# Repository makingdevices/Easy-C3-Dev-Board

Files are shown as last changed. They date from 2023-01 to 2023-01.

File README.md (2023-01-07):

<!-- Improved compatibility of back to top link: See: https://github.com/othneildrew/Best-README-Template/pull/73 -->

<!--
*** Thanks for checking out the Best-README-Template. If you have a suggestion
*** that would make this better, please fork the repo and create a pull request
*** or simply open an issue with the tag "enhancement".
*** Don't forget to give the project a star!
*** Thanks again! Now go create something AMAZING! :D
-->

<!-- PROJECT SHIELDS -->
<!--
*** I'm using markdown "reference style" links for readability.
*** Reference links are enclosed in brackets [ ] instead of parentheses ( ).
*** See the bottom of this document for the declaration of the reference variables
*** for contributors-url, forks-url, etc. This is an optional, concise syntax you may use.
*** https://www.markdownguide.org/basic-syntax/#reference-style-links
-->
[][ig-url]
[][sponsor-url]
[][stars-url]
[][issues-url]
[][linkedin-url]

<!-- PROJECT LOGO -->
<br />
<div align="center">
  <a href="https://makingdevices.com/links/">
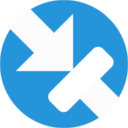
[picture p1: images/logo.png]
    
  </a>

<h3 align="center">Making Devices</h3>

  <p align="center">
    Open Source projects where we struggle with engineering, electronics, coding and who knows what else... In this case, The Easy C3 Dev Board is a development board for the esp32 C3 so I can test their capabilities, so hopefully you may find it interesting ;)
  </p>
</div>

<!-- TABLE OF CONTENTS -->
<details>
  <summary>Table of Contents</summary>
  <ol>
    <li>
      <a href="#about-the-project">About The Project</a>
      <ul>
        <li><a href="#built-with">Built With</a></li>
      </ul>
    </li>
    <li>
      <a href="#Build-one">Build one</a>
      <ul>
      </ul>
    </li>
    <li><a href="#usage">Usage</a></li>
    <li><a href="#roadmap">Roadmap</a></li>
    <li><a href="#license">License</a></li>
    <li><a href="#contact">Contact</a></li>
    <li><a href="#Sponsor">Sponsor</a></li>
  </ol>
</details>

<!-- ABOUT THE PROJECT -->
## About The Project

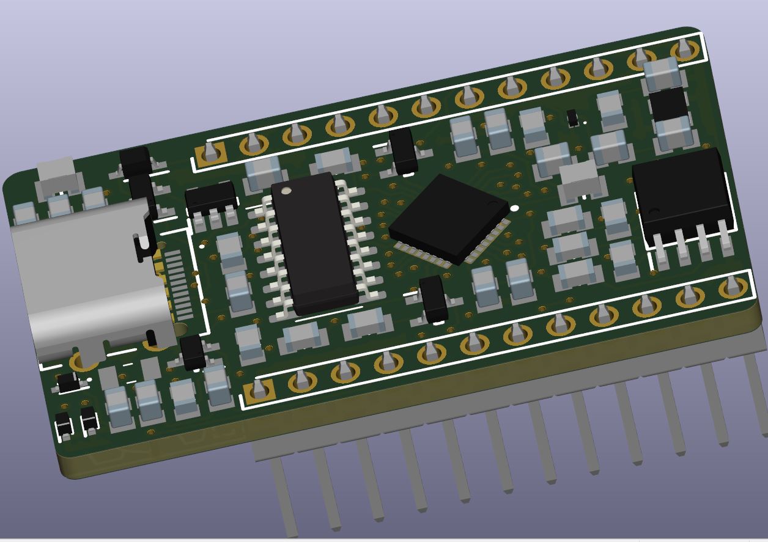
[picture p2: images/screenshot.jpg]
Bytes Counter Shot
[](https://github.com/makingdevices/Easy-C3-Dev-Board)

The Easy C3 Dev Board is a esp32 C3 based development board to test this microcontroller.

This device is under development, so I do encourage you to not assembly, order any PCB or use any software from this repository until the project is finished.

<p align="right">(<a href="#readme-top">back to top</a>)</p>

### Built With

[][kicad-url]
[][sponsor-url]

<p align="right">(<a href="#readme-top">back to top</a>)</p>

<!-- GETTING STARTED -->

## Build one
NOT RECOMMENDED AS THE DEVICE IS UNDER DEVELOPMENT

<p align="right">(<a href="#readme-top">back to top</a>)</p>

<!-- USAGE EXAMPLES -->
## Usage

Instructions of use:

- Not tested

<p align="right">(<a href="#readme-top">back to top</a>)</p>

<!-- ROADMAP -->
## Roadmap

- [ ] Assembly project.
- [ ] Test/validate the board

See the [open issues](https://github.com/makingdevices/Easy-C3-Dev-Board/issues) for a full list of proposed features (and known issues).

State: Project <b>UNFINISHED</b> - 08/01/2023

Priority: <b>Medium</b>

<p align="right">(<a href="#readme-top">back to top</a>)</p>

<!-- LICENSE -->
## License

Distributed under three licenses:
- [Hardware](/License/HW_cern_ohl_s_v2.pdf)
- [Software](/License/SW_GPLv3.0.txt)
- [Documentation](/License/Documentation_CC-BY-SA-4.0.txt)

[GPL v3 License][license-url] 
<p align="right">(<a href="#readme-top">back to top</a>)</p>

<!-- CONTACT -->
## Contact

Making Devices - [@MakingDevices](https://www.instagram.com/makingdevices/)

Project Link: [https://github.com/makingdevices/OpenReflowPlate](https://github.com/makingdevices/Easy-C3-Dev-Board/)

Other Links: [LinkTree](https://makingdevices.com/links/)

<p align="right">(<a href="#readme-top">back to top</a>)</p>

<!-- MARKDOWN LINKS & IMAGES -->
<!-- https://www.markdownguide.org/basic-syntax/#reference-style-links -->
[contributors-shield]: https://img.shields.io/github/contributors/makingdevices/Easy-C3-Dev-Board.svg?style=for-the-badge
[contributors-url]: https://github.com/makingdevices/Easy-C3-Dev-Board/graphs/contributors
[forks-shield]: https://img.shields.io/github/forks/makingdevices/Easy-C3-Dev-Board.svg?style=for-the-badge
[forks-url]: https://github.com/makingdevices/Easy-C3-Dev-Board/network/members
[stars-shield]: https://img.shields.io/github/stars/makingdevices/Easy-C3-Dev-Board.svg?style=for-the-badge
[stars-url]: https://github.com/makingdevices/Easy-C3-Dev-Board/stargazers
[issues-shield]: https://img.shields.io/github/issues/makingdevices/Easy-C3-Dev-Board.svg?style=for-the-badge
[issues-url]: https://github.com/makingdevices/Easy-C3-Dev-Board/issues
[license-shield]: /images/license.png
[license-url]: https://github.com/makingdevices/Easy-C3-Dev-Board/tree/main/License
[linkedin-shield]: https://img.shields.io/badge/-LinkedIn-black.svg?style=for-the-badge&logo=linkedin&colorB=555
[linkedin-url]: https://www.linkedin.com/company/making-devices/
[sponsor-shield]: https://img.shields.io/badge/SPONSOR-PCBWAY-black.svg?style=for-the-badge&colorB=1200
[sponsor-url]: https://www.pcbway.com/?from=makingdevices
[sponsor-screenshot]: /images/PCB_sponsor.png
[product-screenshot]: images/screenshot.jpg
[PIC]: https://img.shields.io/badge/PIC18LF45K50-000000?style=for-the-badge
[PIC-url]: http://ww1.microchip.com/downloads/en/devicedoc/40001350f.pdf
[kicad-shield]: https://img.shields.io/badge/kicad-0b03fc?style=for-the-badge&logo=kicad&logoColor=white
[kicad-url]: https://www.kicad.org/
[YT-screenshot]: images/YT_assembly.PNG
[sponsor-icon]:  https://img.shields.io/badge/-PCBWAY-black.svg?style=for-the-badge&colorB=1200
[ig-shield]: https://img.shields.io/badge/instagram-a83297?style=for-the-badge&logo=instagram&logoColor=white
[ig-url]: https://www.instagram.com/makingdevices/
[MPLAB-C]: https://img.shields.io/badge/MPLAB%20C18-DD0031?style=for-the-badge&logo=C&logoColor=white
[MPLAB-C-url]: https://www.microchip.com/en-us/development-tool/SW006011
[Svelte.dev]: https://img.shields.io/badge/Svelte-4A4A55?style=for-the-badge&logo=svelte&logoColor=FF3E00
[Svelte-url]: https://svelte.dev/
[Laravel.com]: https://img.shields.io/badge/Laravel-FF2D20?style=for-the-badge&logo=laravel&logoColor=white
[Laravel-url]: https://laravel.com
[Bootstrap.com]: https://img.shields.io/badge/Bootstrap-563D7C?style=for-the-badge&logo=bootstrap&logoColor=white
[Bootstrap-url]: https://getbootstrap.com
[JQuery.com]: https://img.shields.io/badge/jQuery-0769AD?style=for-the-badge&logo=jquery&logoColor=white
[JQuery-url]: https://jquery.com

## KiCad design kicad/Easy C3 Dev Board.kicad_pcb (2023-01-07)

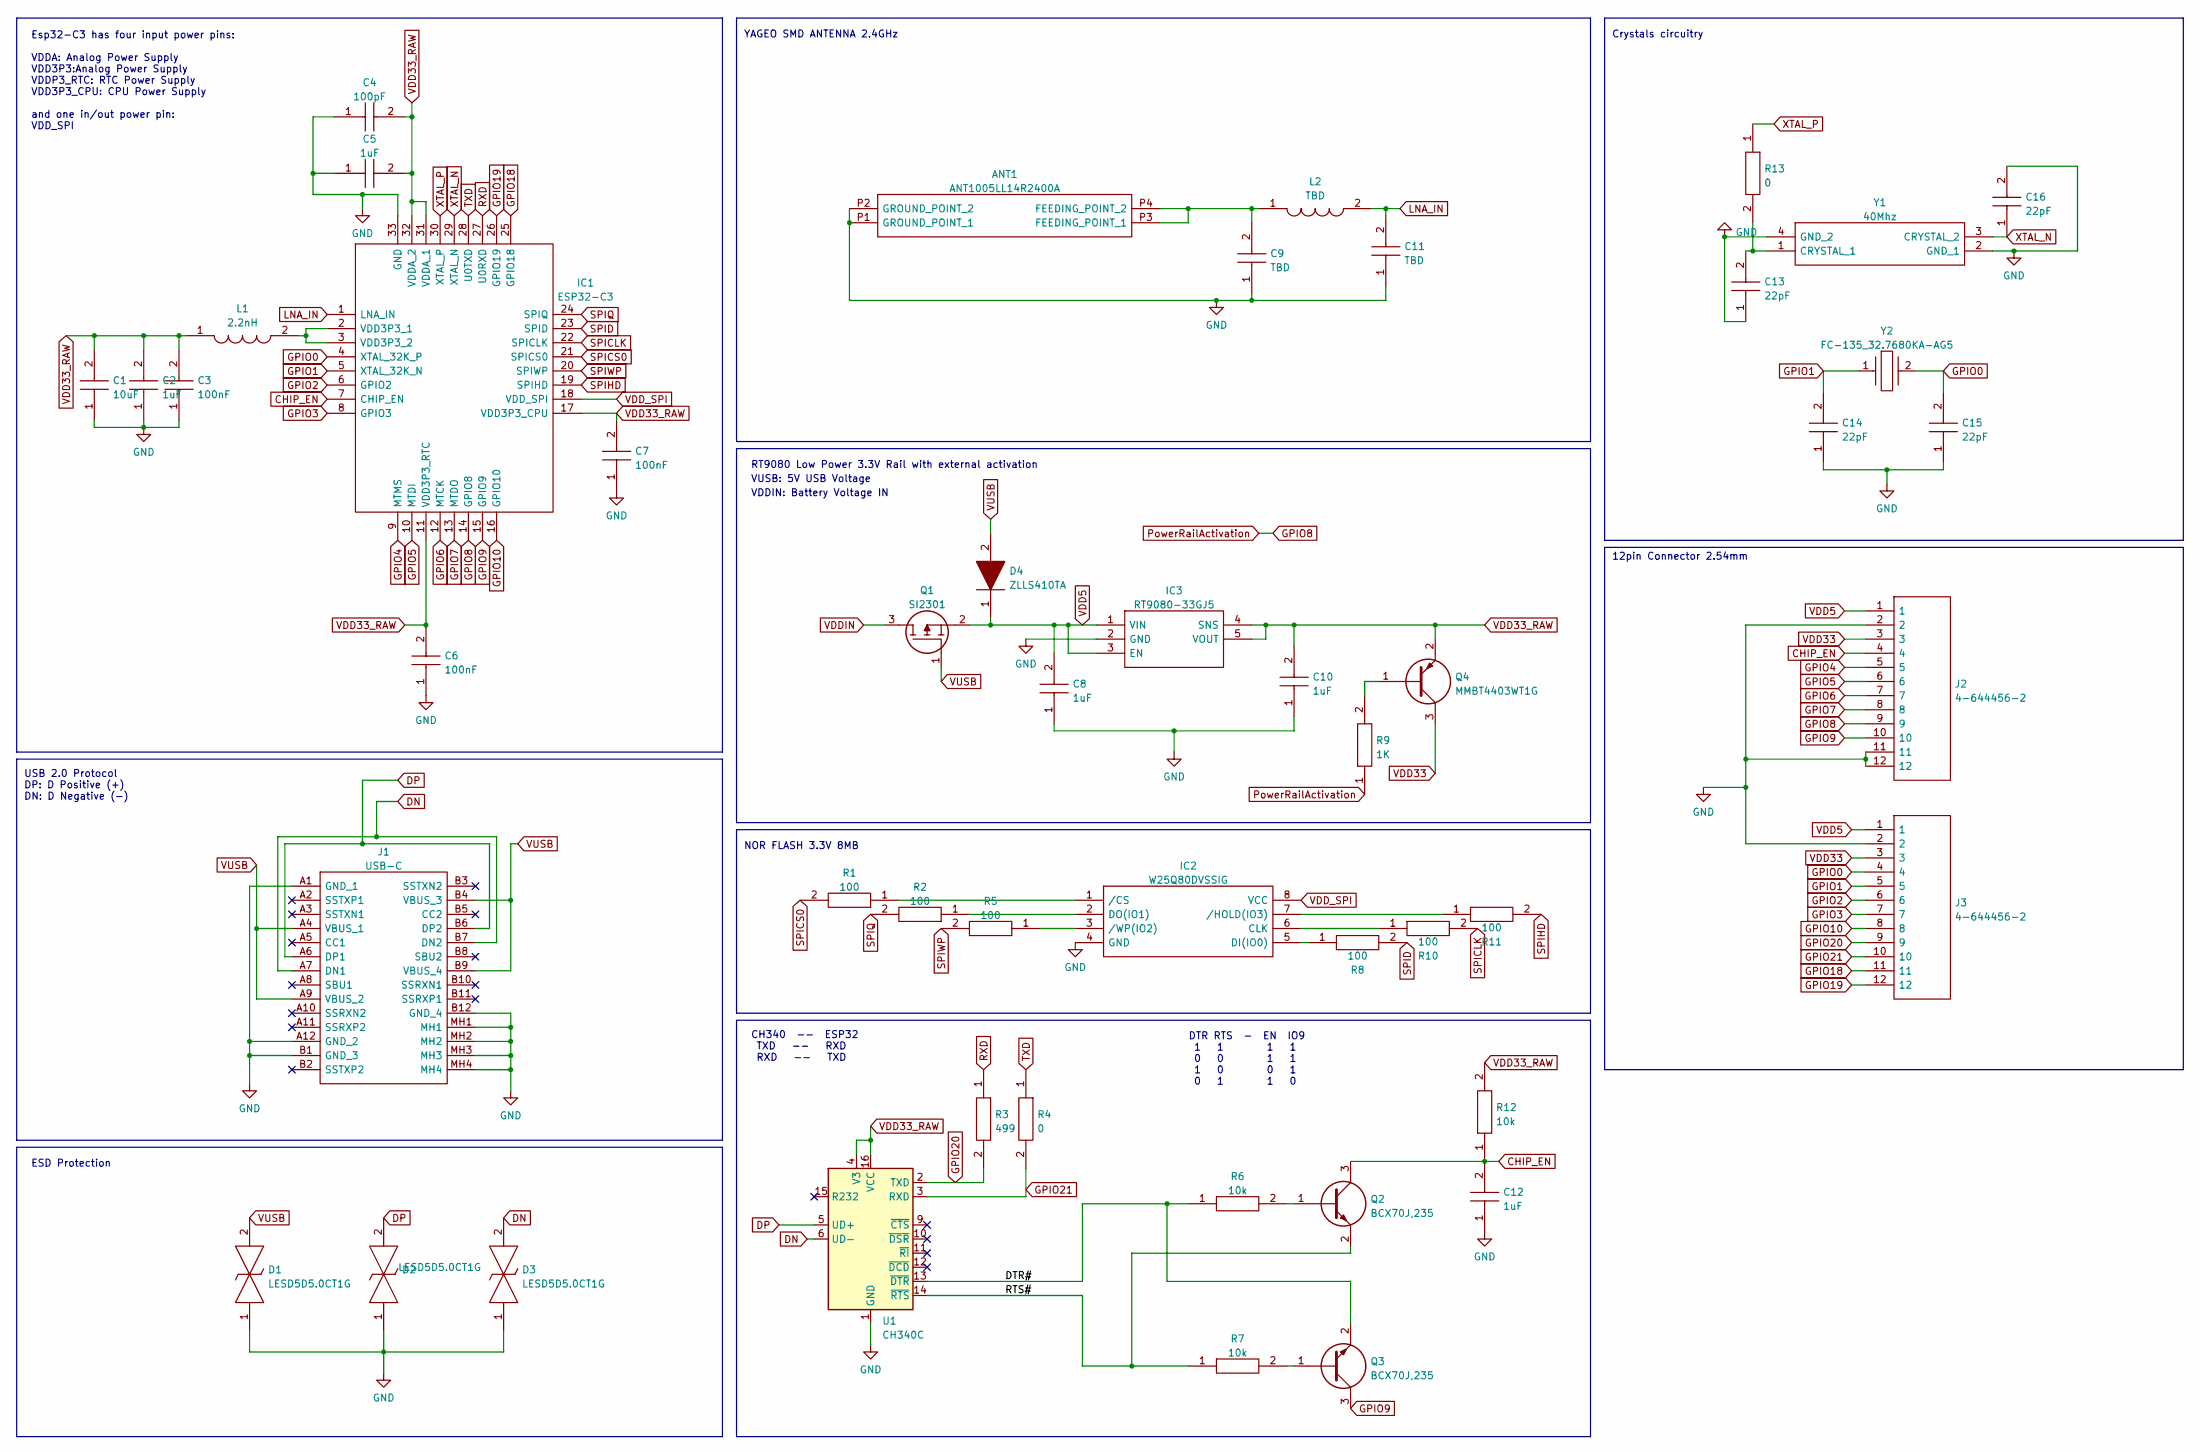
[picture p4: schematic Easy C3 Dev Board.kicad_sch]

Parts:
ANT1: ANT1005LL14R2400A; Mouser Part Number 603-ANT1005LL14R2400
C1: 10uF; CAPC2012X140N; Manufacturer_Part_Number C0805C475M8RACTU
C2, C5, C8, C10, C12: 1uF; CAPC2012X140N; Manufacturer_Part_Number C0805C475M8RACTU
C3, C6, C7: 100nF; CAPC2012X140N; Manufacturer_Part_Number C0805C475M8RACTU
C4: 100pF; CAPC2012X140N; Manufacturer_Part_Number C0805C475M8RACTU
C9, C11: TBD; CAPC2012X140N; Manufacturer_Part_Number C0805C475M8RACTU
C13, C14, C15, C16: 22pF; CAPC2012X140N; Manufacturer_Part_Number C0805C475M8RACTU
D1, D2, D3: LESD5D5.0CT1G; SODFL1608X70N; Manufacturer_Part_Number LESD5D5.0CT1G
D4: ZLLS410TA; SOD2513X120N; Manufacturer_Part_Number ZLLS410TA
IC1: ESP32-C3; QFN50P500X500X90-33N-D; Mouser Part Number 356-ESP32-C3
IC2: W25Q80DVSSIG; SOIC127P790X216-8N; Mouser Part Number 454-W25Q80DVSSIG
IC3: RT9080-33GJ5; SOT94P280X100-5N; Manufacturer_Part_Number RT9080-33GJ5
J1: USB-C; 2171830001; Manufacturer_Part_Number 217183-0001
J2, J3: 4-644456-2; HDRV12W67P0X254_1X12_3018X234X1036P; Mouser Part Number 571-4-644456-2
L1: 2.2nH; LQW2BAN11NG00L; Mouser Part Number 81-LQW2BAS2N7J00L
L2: TBD; LQW2BAN11NG00L; Mouser Part Number 81-LQW2BAS2N7J00L
Q1: SI2301; SOT95P240X120-3N; Manufacturer_Part_Number SI2301
Q2, Q3: BCX70J,235; SOT95P230X110-3N; Mouser Part Number 771-BCX70J235
Q4: MMBT4403WT1G; SOT65P220X100-3N; Mouser Part Number 863-MMBT4403WT1G
R1, R2, R5, R8, R10, R11: 100; RESC2012X75N; Manufacturer_Part_Number ERJP6WF1303V
R3: 499; RESC2012X75N; Manufacturer_Part_Number ERJP6WF1303V
R4, R13: 0; RESC2012X75N; Manufacturer_Part_Number ERJP6WF1303V
R6, R7, R12: 10k; RESC2012X75N; Manufacturer_Part_Number ERJP6WF1303V
R9: 1K; RESC2012X75N; Manufacturer_Part_Number ERJP6WF1303V
U1: CH340C; SOIC-16_3.9x9.9mm_P1.27mm
Y1: 40Mhz; CX2520DB12000D0GPSC1; Manufacturer_Part_Number CX2520DB12000D0GPSC1
Y2: FC-135_32.7680KA-AG5; Q13FC1350000200; Manufacturer_Part_Number FC-135_32.7680KA-AG5

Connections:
/DTR#: Q3.2, R6.1, U1.13 (~DTR)
/RTS#: Q2.2, R7.1, U1.14 (~RTS)
CHIP_EN: C12.2, IC1.7 (CHIP_EN), J2.4, Q2.3, R12.1
DN: D3.2, J1.A7 (DN1), J1.B7 (DN2), U1.6 (UD-)
DP: D2.2, J1.A6 (DP1), J1.B6 (DP2), U1.5 (UD+)
GND: ANT1.P1 (GROUND_POINT_1), ANT1.P2 (GROUND_POINT_2), C1.1, C2.1, C3.1, C4.1, C5.1, C6.1, C7.1, C8.1, C9.1, C10.1, C11.1, C12.1, C13.1, C14.1, C15.1, C16.2, D1.1, D2.1, D3.1, IC1.33 (GND), IC2.4 (GND), IC3.2 (GND), J1.A1 (GND_1), J1.A12 (GND_2), J1.B1 (GND_3), J1.B12 (GND_4), J1.MH1, J1.MH2, J1.MH3, J1.MH4, J2.2, J2.11, J2.12, J3.2, U1.1 (GND), Y1.2 (GND_1), Y1.4 (GND_2)
GPIO0: C15.2, IC1.4 (XTAL_32K_P), J3.4, Y2.2
GPIO1: C14.2, IC1.5 (XTAL_32K_N), J3.5, Y2.1
GPIO2: IC1.6 (GPIO2), J3.6
GPIO3: IC1.8 (GPIO3), J3.7
GPIO4: IC1.9 (MTMS), J2.5
GPIO5: IC1.10 (MTDI), J2.6
GPIO6: IC1.12 (MTCK), J2.7
GPIO7: IC1.13 (MTDO), J2.8
GPIO8: IC1.14 (GPIO8), J2.9, R9.1
GPIO9: IC1.15 (GPIO9), J2.10, Q3.3
GPIO10: IC1.16 (GPIO10), J3.8
GPIO18: IC1.25 (GPIO18), J3.11
GPIO19: IC1.26 (GPIO19), J3.12
GPIO20: J3.9, R3.2, U1.2 (TXD)
GPIO21: J3.10, R4.2, U1.3 (RXD)
LNA_IN: C11.2, IC1.1 (LNA_IN), L2.2
unnamed: ANT1.P3 (FEEDING_POINT_1), ANT1.P4 (FEEDING_POINT_2), C9.2, L2.1
unnamed: C13.2, R13.2, Y1.1 (CRYSTAL_1)
unnamed: IC1.2 (VDD3P3_1), IC1.3 (VDD3P3_2), L1.2
unnamed: IC2.1 (/CS), R1.1
unnamed: IC2.2 (DO(IO1)), R2.1
unnamed: IC2.3 (/WP(IO2)), R5.1
unnamed: IC2.5 (DI(IO0)), R8.1
unnamed: IC2.6 (CLK), R10.1
unnamed: IC2.7 (/HOLD(IO3)), R11.1
unnamed: Q2.1, R6.2
unnamed: Q3.1, R7.2
unnamed: Q4.1, R9.2
RXD: IC1.27 (U0RXD), R3.1
SPICLK: IC1.22 (SPICLK), R10.2
SPICS0: IC1.21 (SPICS0), R1.2
SPID: IC1.23 (SPID), R8.2
SPIHD: IC1.19 (SPIHD), R11.2
SPIQ: IC1.24 (SPIQ), R2.2
SPIWP: IC1.20 (SPIWP), R5.2
TXD: IC1.28 (U0TXD), R4.1
VDD5: C8.2, D4.1, IC3.1 (VIN), IC3.3 (EN), J2.1, J3.1, Q1.2
VDD33: J2.3, J3.3, Q4.3
VDD33_RAW: C1.2, C2.2, C3.2, C4.2, C5.2, C6.2, C7.2, C10.2, IC1.11 (VDD3P3_RTC), IC1.17 (VDD3P3_CPU), IC1.31 (VDDA_1), IC1.32 (VDDA_2), IC3.4 (SNS), IC3.5 (VOUT), L1.1, Q4.2, R12.2, U1.4 (V3), U1.16 (VCC)
VDDIN: Q1.3
VDD_SPI: IC1.18 (VDD_SPI), IC2.8 (VCC)
VUSB: D1.2, D4.2, J1.A4 (VBUS_1), J1.A9 (VBUS_2), J1.B4 (VBUS_3), J1.B9 (VBUS_4), Q1.1
XTAL_N: C16.1, IC1.29 (XTAL_N), Y1.3 (CRYSTAL_2)
XTAL_P: IC1.30 (XTAL_P), R13.1

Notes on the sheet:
RT9080 Low Power 3.3V Rail with external activation
DTR RTS - EN IO9 1 1 1 1 0 0 1 1 1 0 0 1 0 1 1 0
NOR FLASH 3.3V 8MB
12pin Connector 2.54mm
VUSB: 5V USB Voltage
ESD Protection
Esp32-C3 has four input power pins: VDDA: Analog Power Supply VDD3P3:Analog Power Supply VDDP3_RTC: RTC Power Supply VDD3P3_CPU: CPU Power Supply and one in/out power pin: VDD_SPI
YAGEO SMD ANTENNA 2.4GHz
CH340 -- ESP32 TXD -- RXD RXD -- TXD
USB 2.0 Protocol DP: D Positive (+) DN: D Negative (-)
Crystals circuitry
VDDIN: Battery Voltage IN

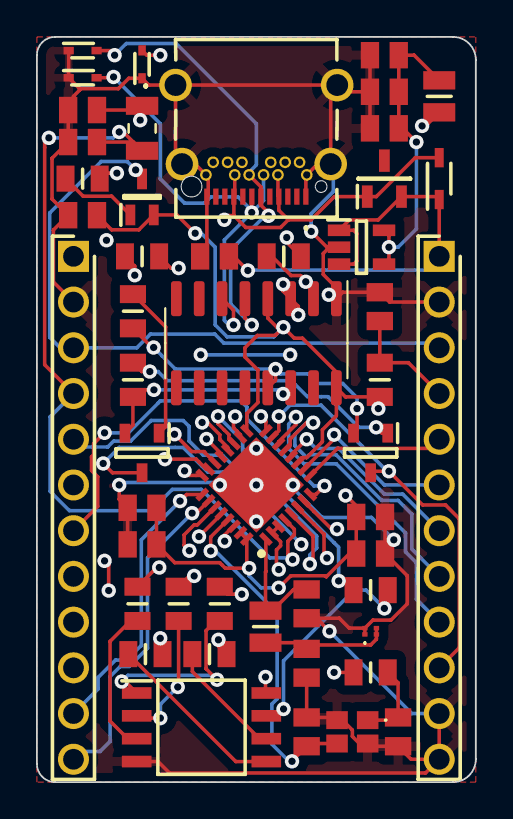
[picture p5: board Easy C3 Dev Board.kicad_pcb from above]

Board: 4 copper layers, 24.4 x 41.4 mm, 49 parts (0 on the bottom side), 49 nets.
